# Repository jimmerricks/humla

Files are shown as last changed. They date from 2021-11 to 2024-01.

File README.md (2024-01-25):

# Humla

The Humla is a 36-key low profile keyboard based on [the Reviung by gtips](https://github.com/gtips/reviung/) and [the Rev-lp by cyril279](https://github.com/cyril279/keyboards/tree/main/revlp). It is for choc switches (with 18x17mm spacing) and has basic support for bluetooth pro micro alternatives such as the [nRFMicro](https://github.com/joric/nrfmicro). Humla means blumblebee in Swedish.

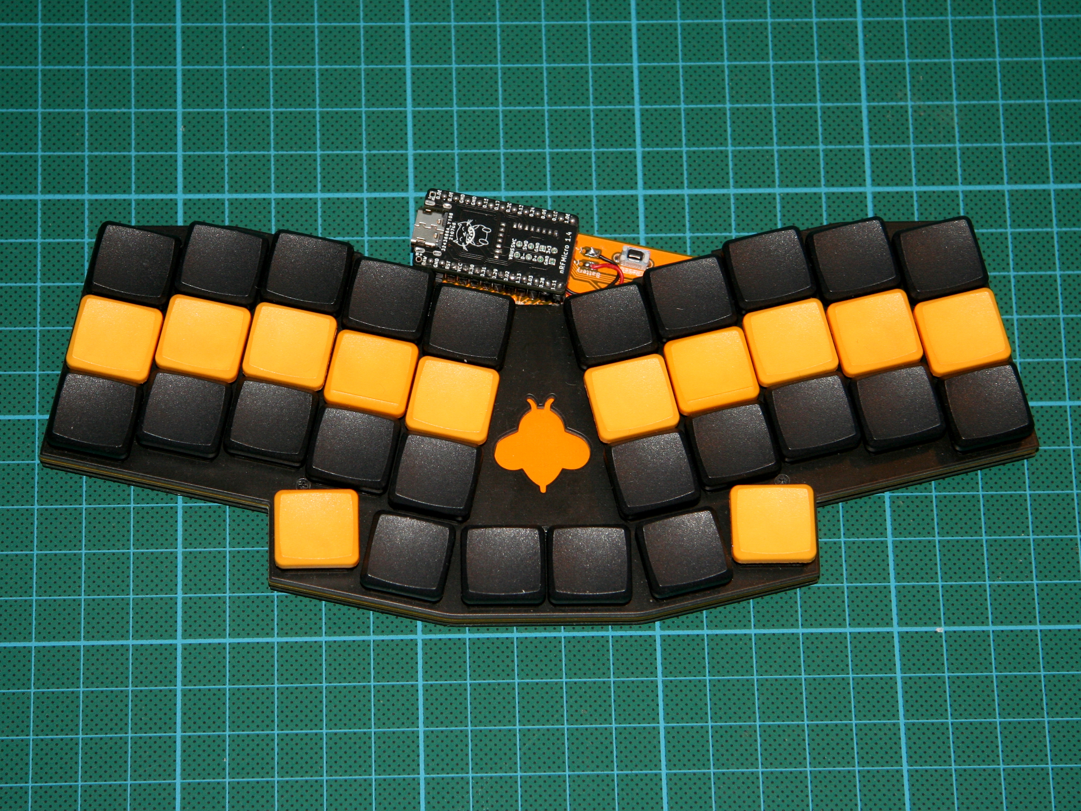
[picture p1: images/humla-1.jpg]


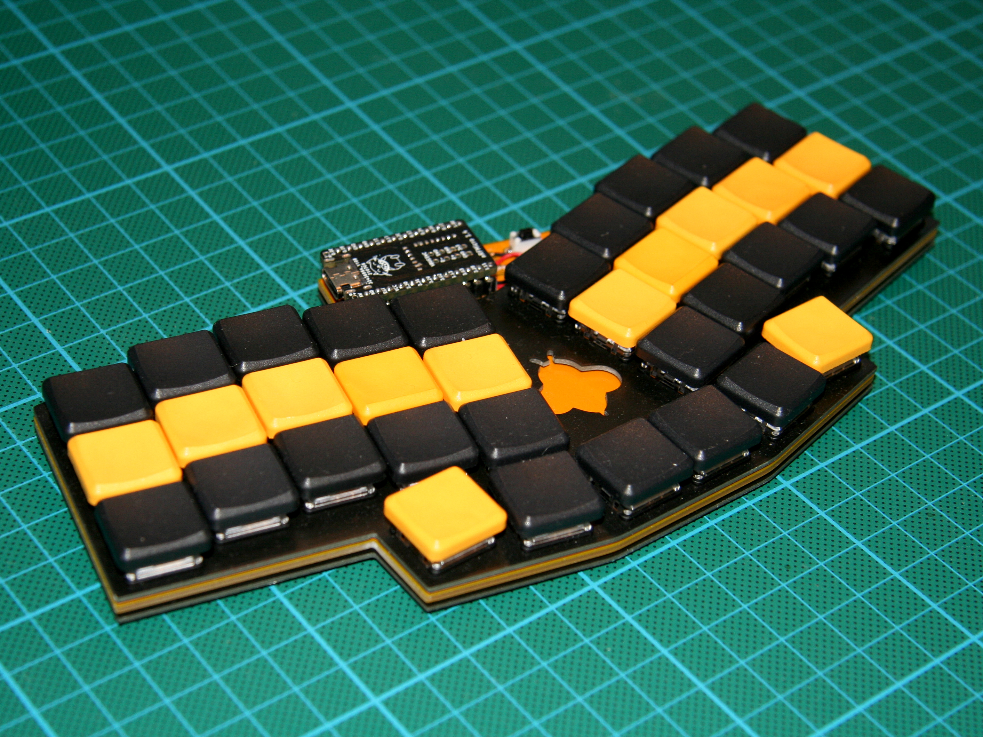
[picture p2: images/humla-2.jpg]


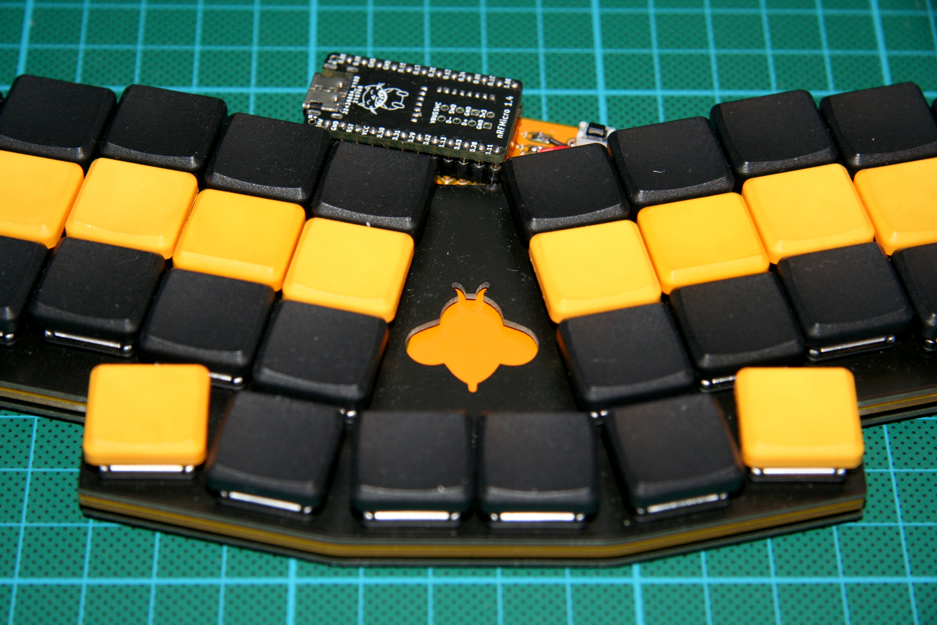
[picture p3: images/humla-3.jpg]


## 3D printed cases

- Basic [case](./case) with cover by [@zzeneg](https://github.com/zzeneg)
- Laptop [adapter](https://github.com/Lenbok/scad-keyboard-cases/tree/master/humla) and bumper by [@Lenbok](https://github.com/Lenbok)

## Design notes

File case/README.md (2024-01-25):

# 3D printed case

Case is supposed to replace base (bottom) plate using the same standoff and screws.

Source file for Fusion 360 is available so it's easy to update parameters for desired thickness, height and hole dimensions.

Default version has 3mm thickness and is optimized for 8x2mm bumpons and M2 screws with 4mm flat heads.

Designed by [@zzeneg](https://github.com/zzeneg).

## Renders

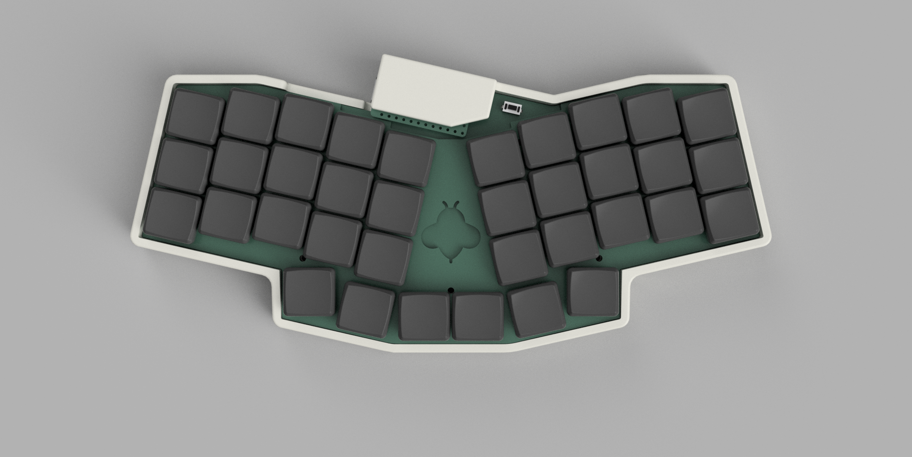
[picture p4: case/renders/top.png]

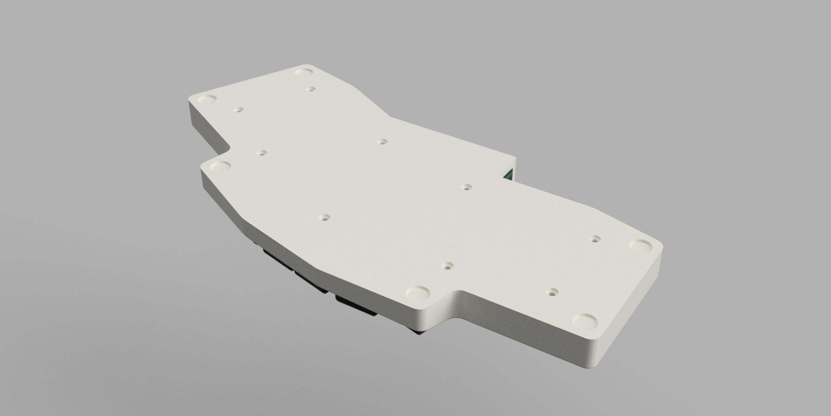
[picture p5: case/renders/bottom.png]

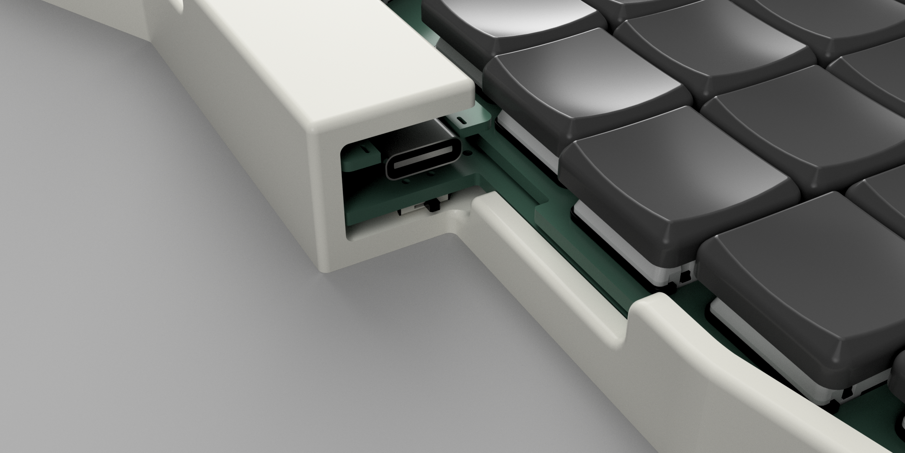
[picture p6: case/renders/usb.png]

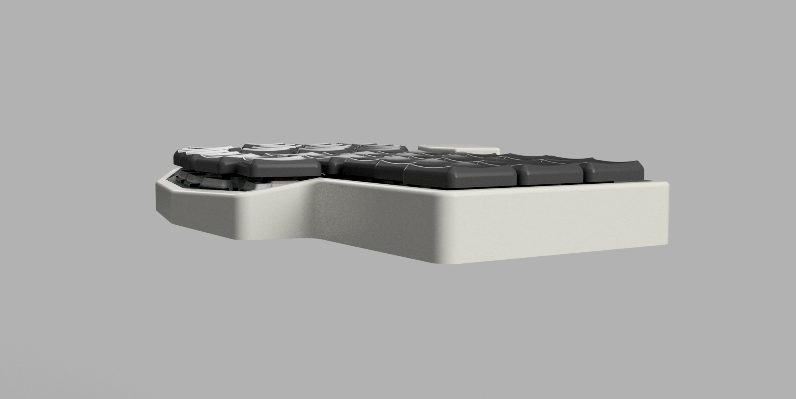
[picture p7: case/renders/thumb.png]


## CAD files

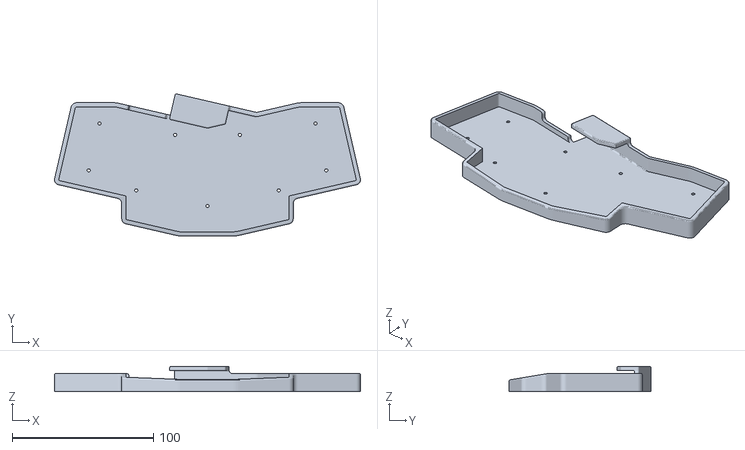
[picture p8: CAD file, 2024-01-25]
case/case.stl
216.6 x 100.6 x 18.0

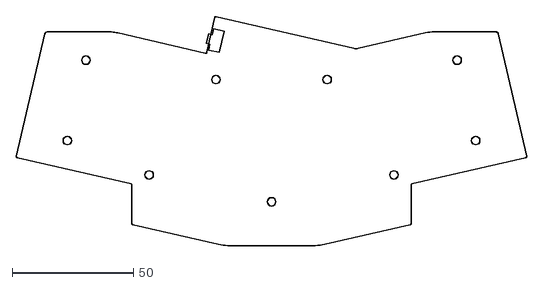
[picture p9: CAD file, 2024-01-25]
case/humla-Edge_Cuts.dxf
210.3 x 94.4

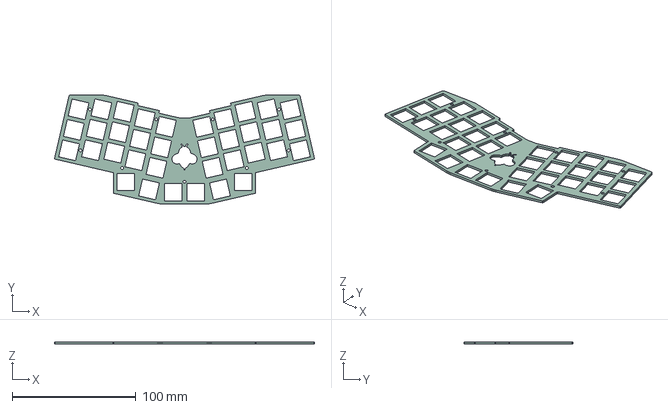
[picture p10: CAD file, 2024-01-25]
case/humla-switch-plate.step
210.2 x 88.0 x 1.60 mm

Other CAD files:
case/case v6.f3z

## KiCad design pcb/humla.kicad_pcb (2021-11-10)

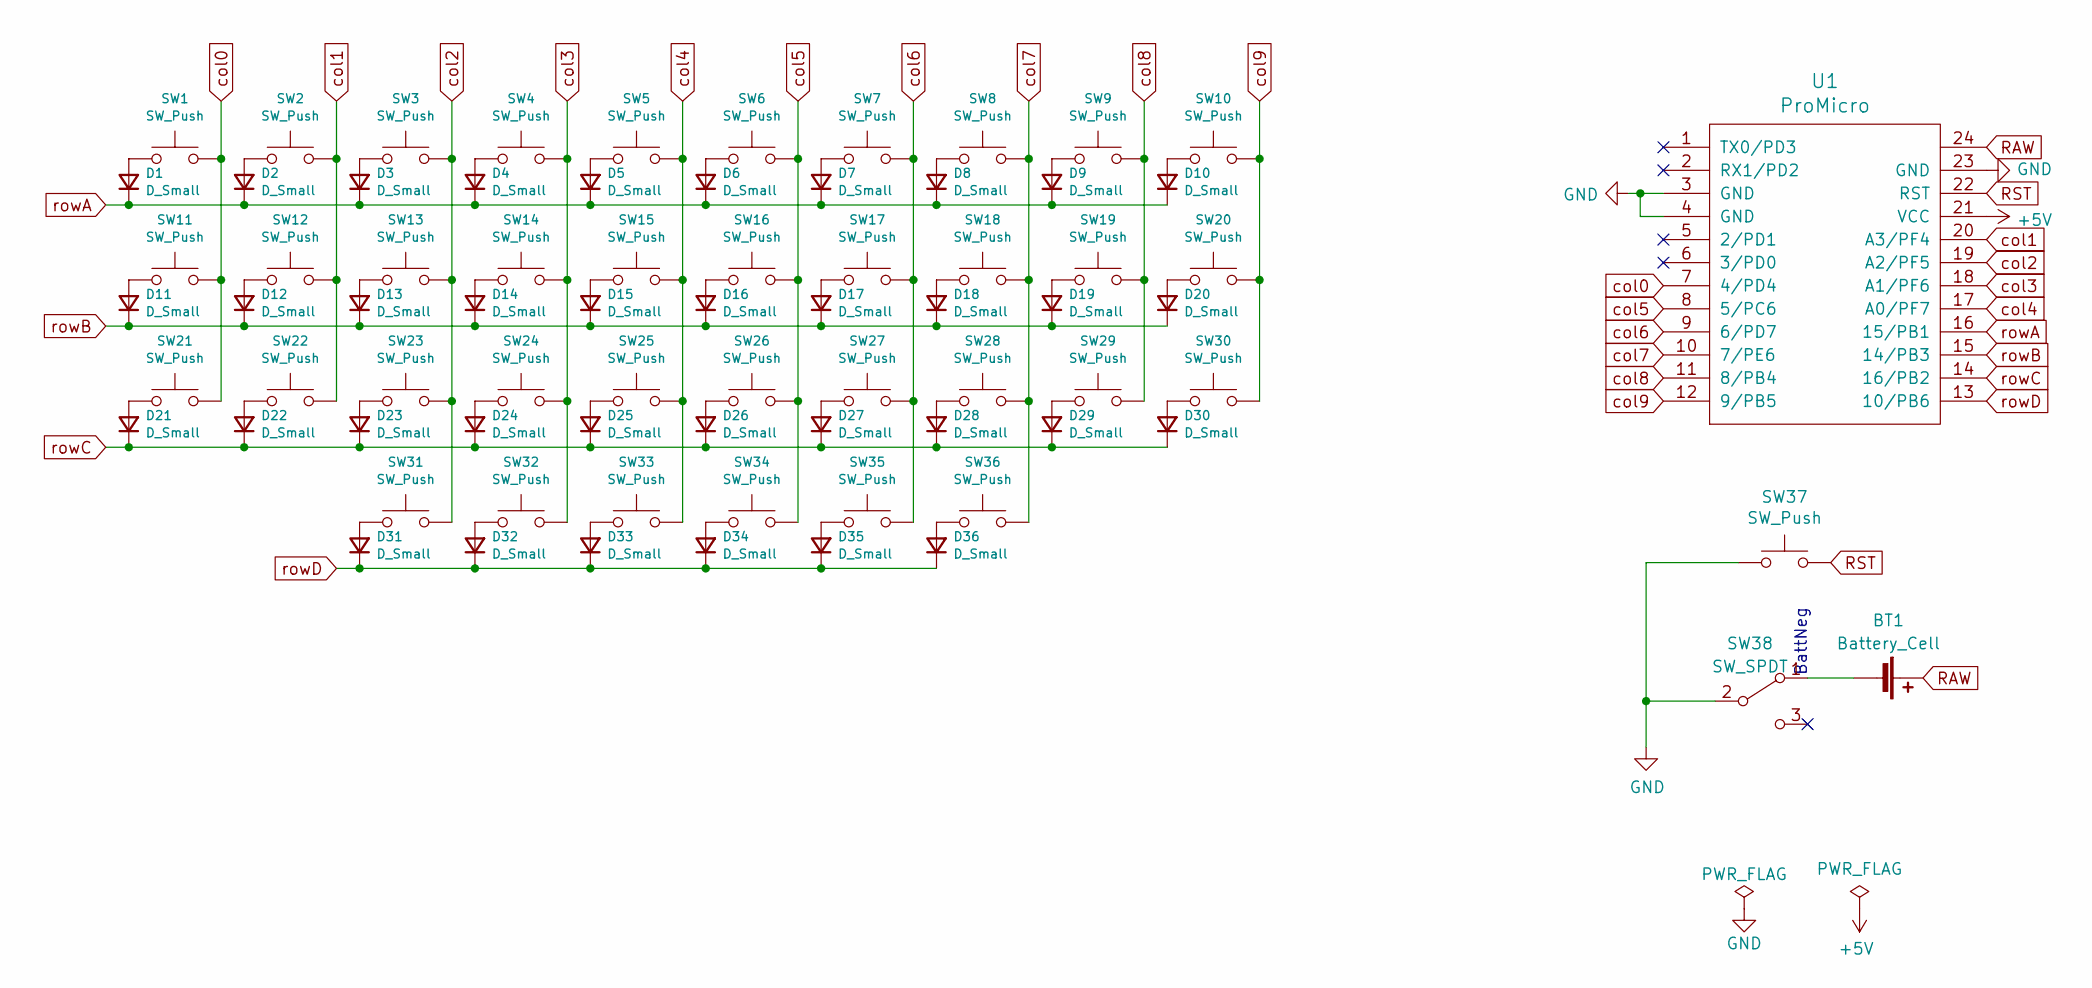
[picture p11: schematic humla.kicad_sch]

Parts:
BT1: Battery_Cell; Battery_pads
D1, D2, D3, D4, D5, D6, D7, D8, D9, D10, D11, D12, D13, D14, D15, D16, D17, D18, D19, D20, D21, D22, D23, D24, D25, D26, D27, D28, D29, D30, D31, D32, D33, D34, D35, D36: D_Small; D3_SMD
SW1, SW2, SW3, SW4, SW5, SW6, SW7, SW8, SW9, SW10, SW11, SW12, SW13, SW14, SW15, SW16, SW17, SW18, SW19, SW20, SW21, SW22, SW23, SW24, SW25, SW26, SW27, SW28, SW29, SW30, SW31, SW32, SW33, SW34, SW35, SW36: SW_Push; Choc
SW37: SW_Push; Reset
SW38: SW_SPDT; power_switch
U1: ProMicro; ArduinoProMicro

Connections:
+5V: U1.21 (VCC)
GND: SW37.1, SW38.2 (B), U1.3 (GND), U1.4 (GND), U1.23 (GND)
unnamed: BT1.2 (-), SW38.1 (A)
unnamed: D1.2 (A), SW1.1
unnamed: D2.2 (A), SW2.1
unnamed: D3.2 (A), SW3.1
unnamed: D4.2 (A), SW4.1
unnamed: D5.2 (A), SW5.1
unnamed: D6.2 (A), SW6.1
unnamed: D7.2 (A), SW7.1
unnamed: D8.2 (A), SW8.1
unnamed: D9.2 (A), SW9.1
unnamed: D10.2 (A), SW10.1
unnamed: D11.2 (A), SW11.1
unnamed: D12.2 (A), SW12.1
unnamed: D13.2 (A), SW13.1
unnamed: D14.2 (A), SW14.1
unnamed: D15.2 (A), SW15.1
unnamed: D16.2 (A), SW16.1
unnamed: D17.2 (A), SW17.1
unnamed: D18.2 (A), SW18.1
unnamed: D19.2 (A), SW19.1
unnamed: D20.2 (A), SW20.1
unnamed: D21.2 (A), SW21.1
unnamed: D22.2 (A), SW22.1
unnamed: D23.2 (A), SW23.1
unnamed: D24.2 (A), SW24.1
unnamed: D25.2 (A), SW25.1
unnamed: D26.2 (A), SW26.1
unnamed: D27.2 (A), SW27.1
unnamed: D28.2 (A), SW28.1
unnamed: D29.2 (A), SW29.1
unnamed: D30.2 (A), SW30.1
unnamed: D31.2 (A), SW31.1
unnamed: D32.2 (A), SW32.1
unnamed: D33.2 (A), SW33.1
unnamed: D34.2 (A), SW34.1
unnamed: D35.2 (A), SW35.1
unnamed: D36.2 (A), SW36.1
RAW: BT1.1 (+), U1.24
RST: SW37.2, U1.22 (RST)
col0: SW1.2, SW11.2, SW21.2, U1.7 (4/PD4)
col1: SW2.2, SW12.2, SW22.2, U1.20 (A3/PF4)
col2: SW3.2, SW13.2, SW23.2, SW31.2, U1.19 (A2/PF5)
col3: SW4.2, SW14.2, SW24.2, SW32.2, U1.18 (A1/PF6)
col4: SW5.2, SW15.2, SW25.2, SW33.2, U1.17 (A0/PF7)
col5: SW6.2, SW16.2, SW26.2, SW34.2, U1.8 (5/PC6)
col6: SW7.2, SW17.2, SW27.2, SW35.2, U1.9 (6/PD7)
col7: SW8.2, SW18.2, SW28.2, SW36.2, U1.10 (7/PE6)
col8: SW9.2, SW19.2, SW29.2, U1.11 (8/PB4)
col9: SW10.2, SW20.2, SW30.2, U1.12 (9/PB5)
rowA: D1.1 (K), D2.1 (K), D3.1 (K), D4.1 (K), D5.1 (K), D6.1 (K), D7.1 (K), D8.1 (K), D9.1 (K), D10.1 (K), U1.16 (15/PB1)
rowB: D11.1 (K), D12.1 (K), D13.1 (K), D14.1 (K), D15.1 (K), D16.1 (K), D17.1 (K), D18.1 (K), D19.1 (K), D20.1 (K), U1.15 (14/PB3)
rowC: D21.1 (K), D22.1 (K), D23.1 (K), D24.1 (K), D25.1 (K), D26.1 (K), D27.1 (K), D28.1 (K), D29.1 (K), D30.1 (K), U1.14 (16/PB2)
rowD: D31.1 (K), D32.1 (K), D33.1 (K), D34.1 (K), D35.1 (K), D36.1 (K), U1.13 (10/PB6)

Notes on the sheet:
BattNeg

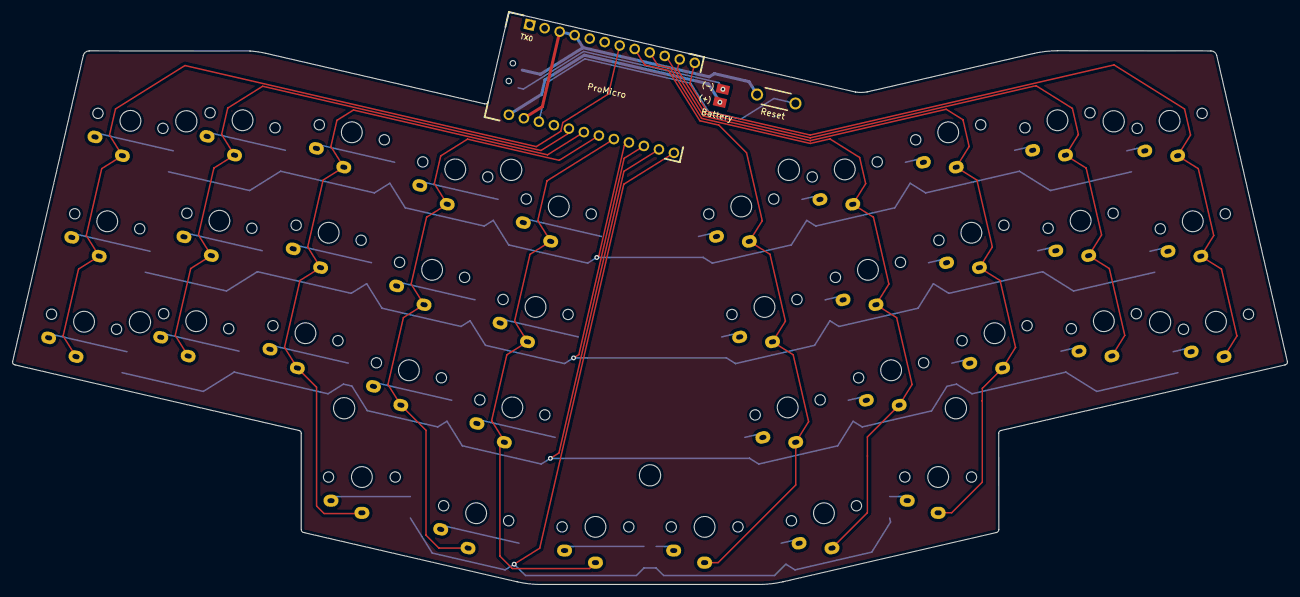
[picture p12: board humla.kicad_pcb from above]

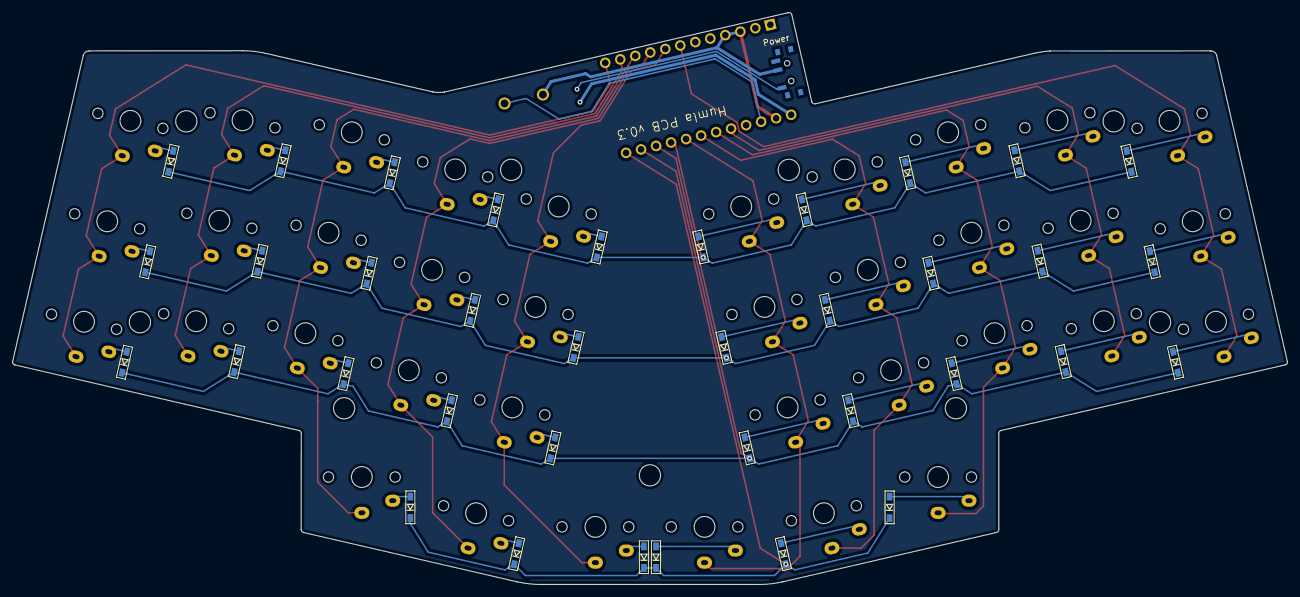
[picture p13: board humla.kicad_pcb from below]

Board: 2 copper layers, 210.2 x 94.3 mm, 85 parts (38 on the bottom side), 54 nets.

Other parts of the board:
h2, h2#2, h2#3, h2#4, h2#5, h2#6, h2#7, h2#8, h2#9: h2; M2_hole_3.5mm

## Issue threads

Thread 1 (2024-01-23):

Power switch hardware

levouh, 2024-01-23:
Awesome design - got a few PCBs printed and I have _almost_ all the necessary parts.

**I am curious what is intended to be used for the power button?**

It appears to be a surface mount part on the bottom side of the board with 4-8 contacts? I see the footprint labeled as SW38 on the PCB in KiCAD, but some naive research doesn't show up with much for that.

For anyone else who stumbles here, this is what I ended up needing as far as materials go:

* 1x Microcontroller (nice!nano)
* 1x Battery 3.7v lithium rechargeable battery, 301230 110 mAh
* 1x 2-pin through-hole reset switch
* 36x Surface mount diodes
* 36x Choc Switches
* 36x Choc Keycaps

jimmerricks, 2024-01-23:
The 7 pin slide switch (eg, MSK12C02)?

levouh, 2024-01-23:
Yes, that one. I should have included a screenshot.

The main purpose is then to connect the battery to the controller when in one position, and disconnect it when in the "off" position then, right? So when plugged in, the keyboard works regardless. The switch needs to be in a "connected" state to charge the battery, and when unplugged to have power, etc.

Is that understanding correct?

jimmerricks, 2024-01-24:
Sound right. I'd have to double check but I think it achieves this by connecting the battery to GND.

Closed 2024-01-24.

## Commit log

2021-11-10 Initial commit of Humla source files.
    [humla-base-plate.kicad_pcb, humla-switch-plate.kicad_pcb, humla.kicad_pcb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]
2024-01-22 add case
    [case v2.f3z, case.stl, humla-Edge_Cuts.dxf]
2024-01-24 case: add cut for USB cable, remove area around USB port to allow longer MCUs
    [case v2.f3z, case v4.f3z, case.stl]
2024-01-24 case: renders and readme
    [case v4.f3z, case v6.f3z, case.stl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]
